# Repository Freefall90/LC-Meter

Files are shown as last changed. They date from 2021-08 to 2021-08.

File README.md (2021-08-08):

# LC-Meter
Hardware design files for an inductance and capacitance meter

The STLs are exports from the STEP file. The other folders contain STEP files for the external components (a switch and the LCD).

There's also a very unfinished plated through hole version of the board (the PTH variant). I started on that before I figured out the problem with the weird oscillations and never finished it since the SMD board works fine with the added cap. 

# Attributions
The circuit design and firmware are courtesy of Phil Rice (VK3BHR) at https://sites.google.com/site/vk3bhr/home/index2-html

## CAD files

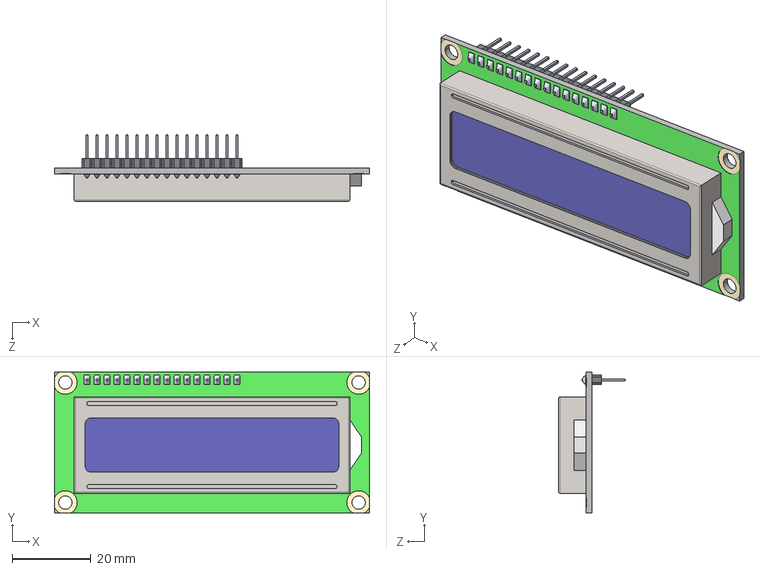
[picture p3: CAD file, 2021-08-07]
LCD16X2/LCD 16X2.STEP
80.0 x 35.8 x 16.9 mm

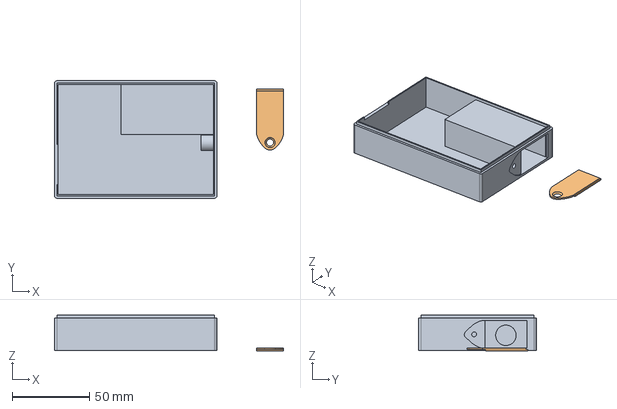
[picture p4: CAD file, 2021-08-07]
Meter Case v15.step
148.0 x 76.0 x 23.1 mm
Case Body Back
Battery cover

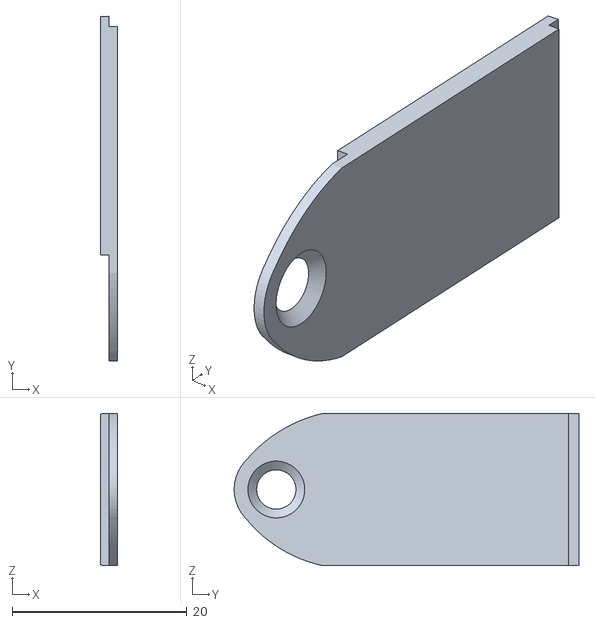
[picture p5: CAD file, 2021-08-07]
STL/Battery cover v4.stl
2.00 x 39.4 x 17.4

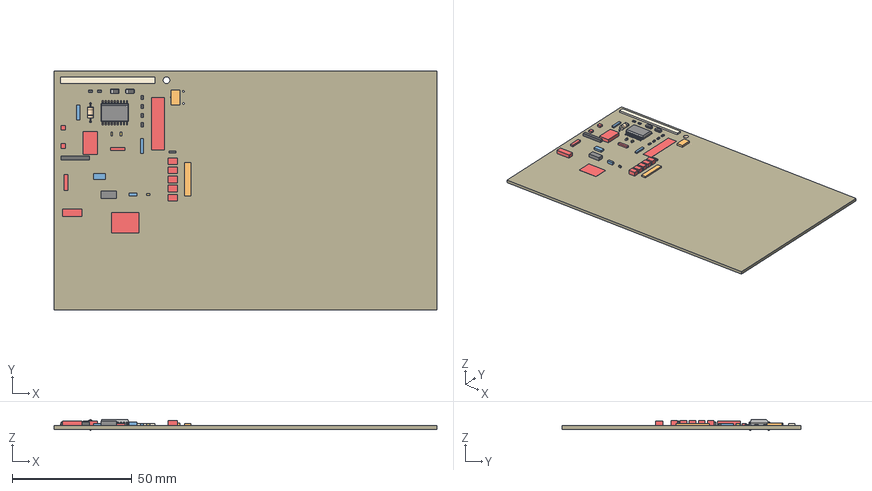
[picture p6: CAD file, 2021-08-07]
LC Meter pcb.step
160.0 x 100.0 x 4.42 mm
Board
22uF
C0603 x 3
10uF x 2
10uF_1
C050-035X075 x 2
1N4004
SOD-323F
AB9V
PIC16F628SO
JP1 x 5
0207/7
1X01 x 2
HC49/S
100k x 6
RTRIM3339P
EG1218
REEDRELAY
HD44780LCD-1602
SIL6
OS202011MS2QS1
B3F-10XX

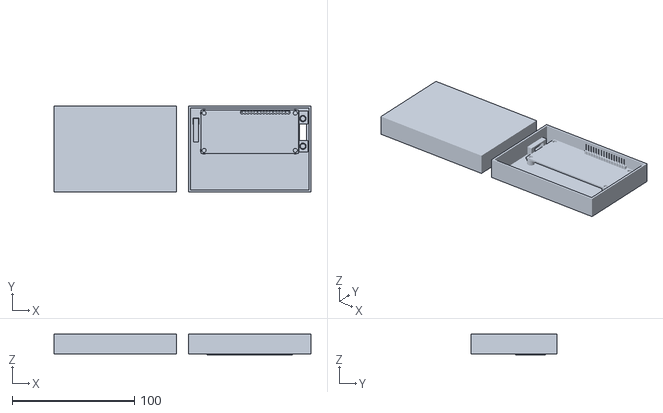
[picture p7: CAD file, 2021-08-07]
STL/Meter Case v2.stl
210.0 x 70.0 x 16.9

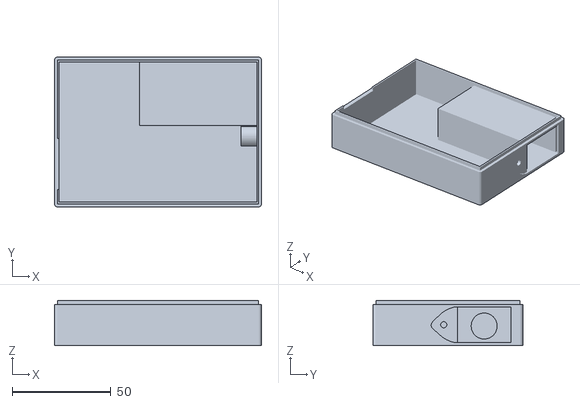
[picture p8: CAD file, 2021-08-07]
STL/Case Body Back v5.stl
105.0 x 76.0 x 23.0

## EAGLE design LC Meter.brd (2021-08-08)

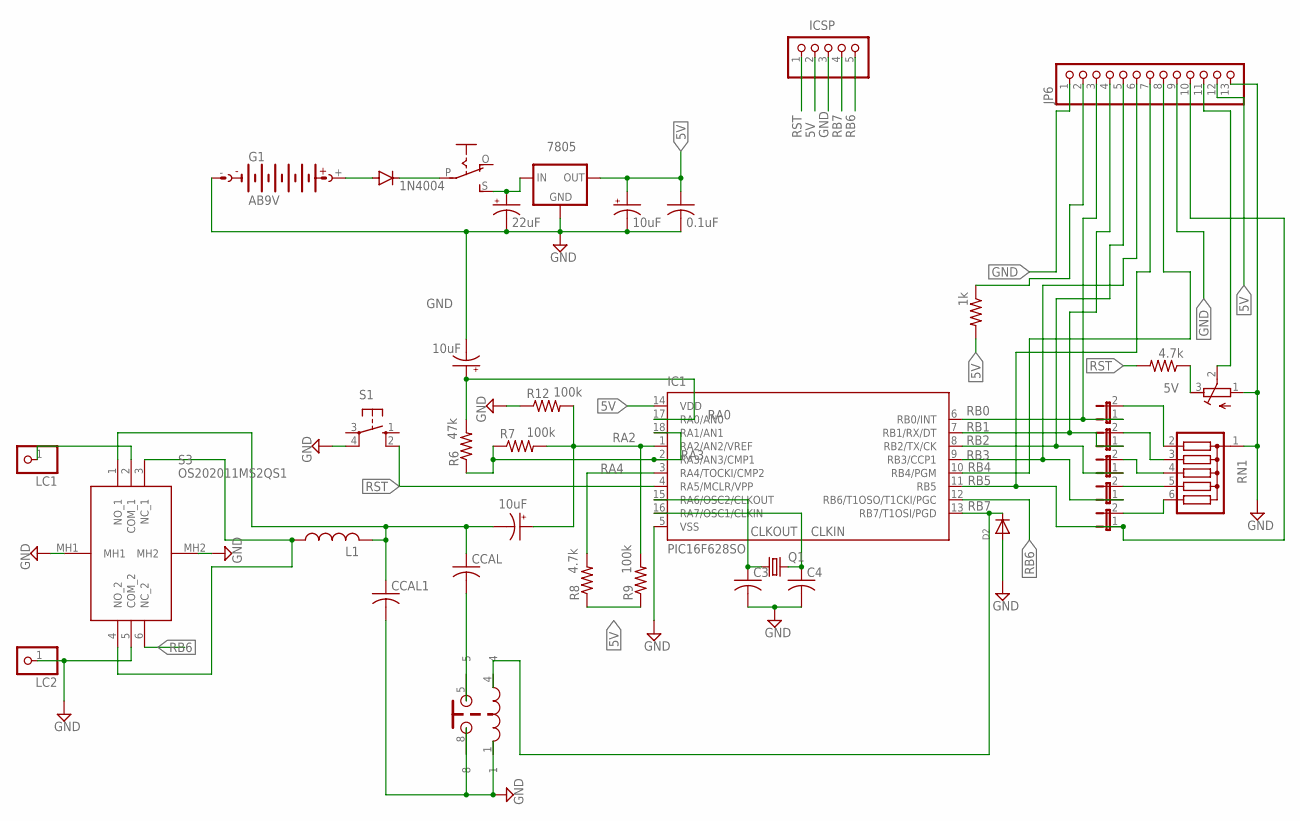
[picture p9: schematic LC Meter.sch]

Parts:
C1: 22uF; B/3528-21R
C2: 0.1uF; C0603
C3, C4: C-USC0603; C0603
C5, C6, C7: 10uF; E2-4
CCAL, CCAL1: C-US050-035X075; C050-035X075
D1: 1N4004; DO41-10
D2: DIODEDO-1N4148; DO-1N4148
G1: AB9V
IC1: PIC16F628SO; SO-18W
ICSP: PINHD-1X5; 1X05
JP1, JP2, JP3, JP4, JP5: JP1E; JP1
JP6: PINHD-1X13; 1X13
L1: L-US0207/12; 0207/12
LC1, LC2: PINHD-1X1; 1X01
Q1: CRYSTALHC49S; HC49/S
R1: 1k; R0603
R6: 47k; 0204/7
R7, R9, R12: 100k; 0204/7
R8, R10: 4.7k; 0204/7
R11: R-TRIMM3339P; RTRIM3339P
REED: REEDRELAY; COTO2204
RN1: G05R; SIL6
S1: 10-XX; B3F-10XX
S2: EG1218S; EG1218
S3: OS202011MS2QS1
VREG: 7805; 78XXS

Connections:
5V: C2.1, C6.+, IC1.14 (VDD), ICSP.2, JP6.12, R1.2, R8.1, R9.1, R10.1, R11.3 (E), VREG.OUT
CLKIN: C4.1, IC1.16 (RA7/OSC1/CLKIN), Q1.2
CLKOUT: C3.1, IC1.15 (RA6/OSC2/CLKOUT), Q1.1
GND: C1.-, C2.2, C3.2, C4.2, C6.-, C7.-, CCAL1.2, D2.A, G1.-, IC1.5 (VSS), ICSP.3, JP6.1, JP6.9, JP6.13, LC2.1, R11.1 (A), R12.1, REED.1, REED.8, RN1.1, S1.4 (P1), S3.5 (COM_2), S3.MH1, S3.MH2, VREG.GND
unnamed: JP5.2, RN1.6
unnamed: CCAL.2, REED.5
unnamed: C1.+, S2.S, VREG.IN
unnamed: D1.C, S2.P
unnamed: D1.A, G1.+
unnamed: C5.-, CCAL.1, CCAL1.1, L1.2, S3.1 (NO_1)
unnamed: JP4.2, RN1.5
unnamed: JP3.2, RN1.4
unnamed: JP2.2, RN1.3
unnamed: JP1.2, RN1.2
unnamed: LC1.1, S3.2 (COM_1)
unnamed: L1.1, S3.3 (NC_1), S3.4 (NO_2)
unnamed: JP6.11, R11.2 (S)
unnamed: JP6.2, R1.1
RA0: C7.+, IC1.17 (RA0/AN0), R6.2
RA2: C5.+, IC1.1 (RA2/AN2/VREF), R7.2, R9.2, R12.2; also elsewhere on the board
RA3: IC1.2 (RA3/AN3/CMP1), IC1.18 (RA1/AN1), R6.1, R7.1; also elsewhere on the board
RA4: IC1.3 (RA4/TOCKI/CMP2), R8.2
RB0: IC1.6 (RB0/INT), JP1.1, JP6.3
RB1: IC1.7 (RB1/RX/DT), JP2.1, JP6.4
RB2: IC1.8 (RB2/TX/CK), JP3.1, JP6.5
RB3: IC1.9 (RB3/CCP1), JP4.1, JP6.6
RB4: IC1.10 (RB4/PGM), JP6.8
RB5: IC1.11 (RB5), JP5.1, JP6.7, JP6.10
RB6: IC1.12 (RB6/T1OSO/T1CKI/PGC), ICSP.5, S3.6 (NC_2)
RB7: D2.C, IC1.13 (RB7/T1OSI/PGD), ICSP.4, REED.4
RST: IC1.4 (RA5/MCLR/VPP), ICSP.1, R10.2, S1.2 (S1)

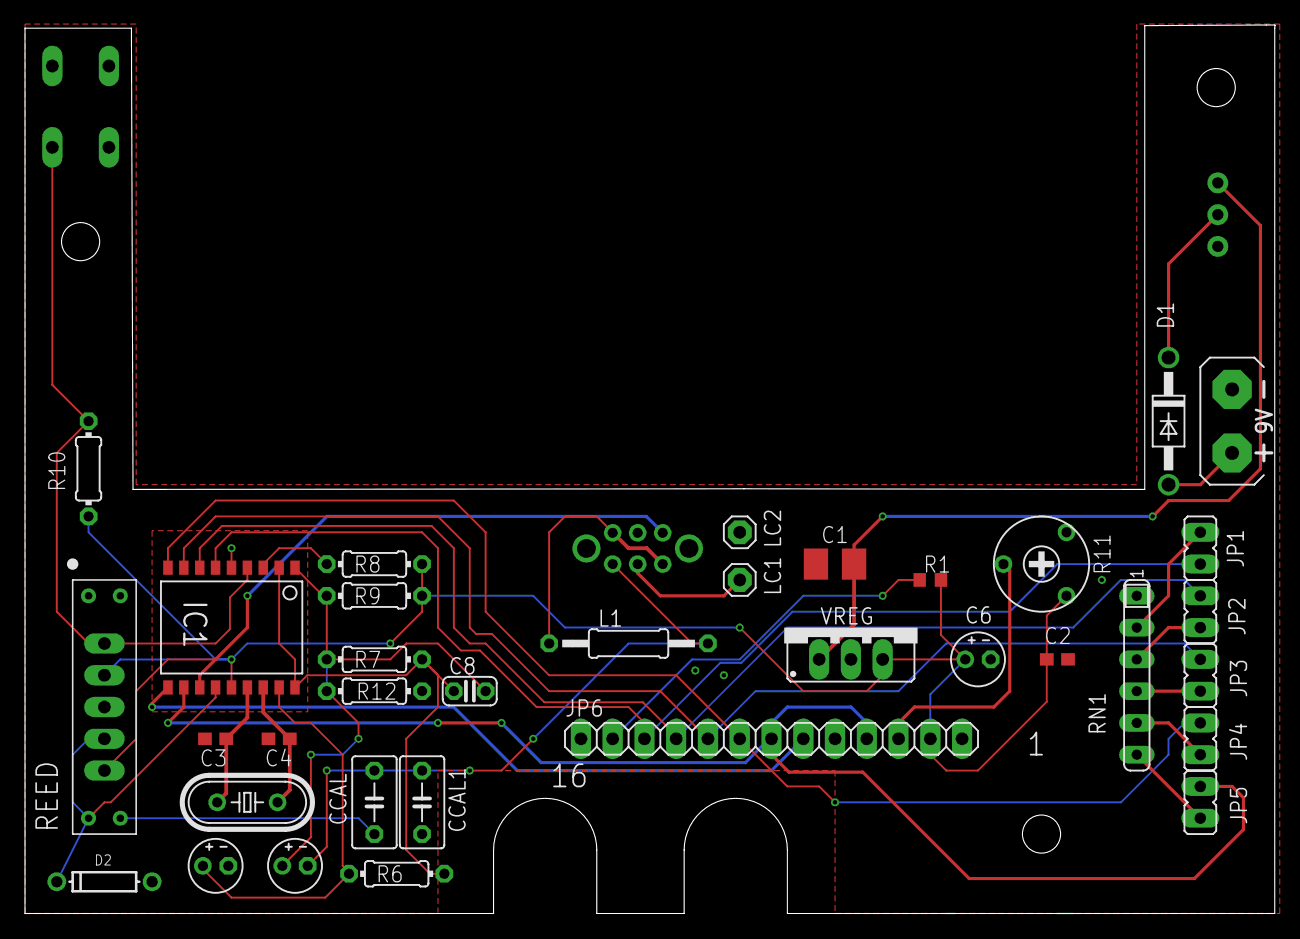
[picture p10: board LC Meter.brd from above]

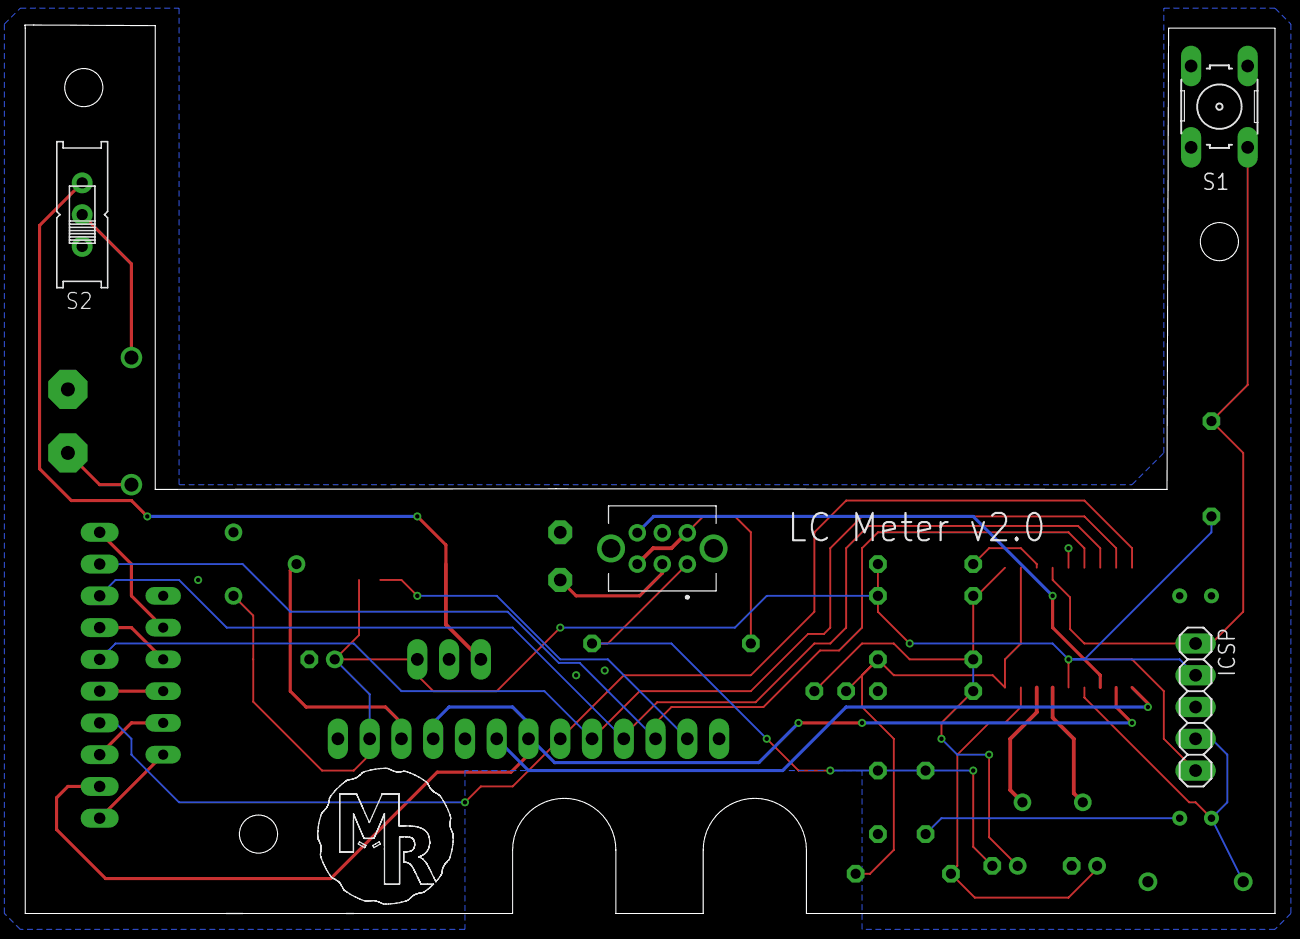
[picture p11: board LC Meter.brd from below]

Board: 2 copper layers, 99.9 x 71.0 mm, 39 parts (4 on the bottom side), 31 nets.

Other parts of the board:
C8: 10pF; C025-024X044

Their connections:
RA2: C8.2; also elsewhere on the board
RA3: C8.1; also elsewhere on the board

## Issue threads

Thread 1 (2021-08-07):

Add BOM

Freefall90, 2021-08-07:
Some junk box components in here that won't be obvious.

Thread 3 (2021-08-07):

Unstable oscillations causing meter readings to fluctuate wildly

Freefall90, 2021-08-07:

Freefall90, 2021-08-07:
This can be fixed by placing a 10pF ceramic cap across R7 (I had no luck putting it directly across pins 1 & 2 of the PIC, but YMMV). Should update the schematic and board with an optional DNP cap.

Freefall90, 2021-08-08:
Fixed as of commit cf0c7e8907c82402d8763d6b2dd8b187a8e2d4bd

Closed 2021-08-08.

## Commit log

2021-08-07 Moved STLs
    [Battery cover v4.stl, Case Body Back v5.stl, Meter Case v2.stl]
2021-08-08 Fix for iCloud symlink issue
    [LC Meter PTH.brd, LC Meter PTH.sch, LC Meter.brd]
